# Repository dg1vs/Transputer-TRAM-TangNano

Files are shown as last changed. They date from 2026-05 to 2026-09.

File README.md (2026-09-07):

# Transputer-TRAM-TangNano

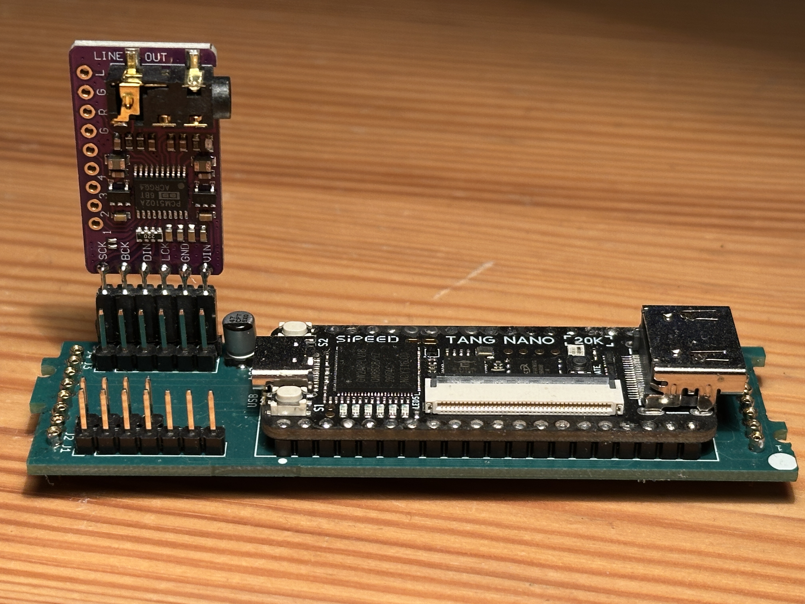
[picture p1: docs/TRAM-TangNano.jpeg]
Transputer-TRAM-TangNano V02


A **TRAM-size FPGA Transputer module** based on the **Sipeed Tang Nano 20K**.

The goal of this project is to provide a modern, compact Transputer module which can be used in systems designed for classic INMOS TRAMs, while replacing most of the increasingly difficult-to-obtain historical hardware with an FPGA implementation.

The project targets FPGA implementations of the **T805** and **T425** Transputers and is intended both for practical use in existing Transputer systems and for experimenting with Transputer hardware today.

The main idea behind this project is to provide a TRAM with an FPGA based implementation. For FPGA imlemetation please see the paper [1]. 

## Main Features

- TRAM-size PCB
- Sipeed **Tang Nano 20K** FPGA module
- FPGA implements the **INMOS T805 and T425**
- Standard Transputer link interface
- Four Transputer links
- Support for the usual TRAM control signals
- 5 V / 3.3 V level adaptation between classic Transputer hardware and the FPGA
- I²S audio support
- Selected Transputer and FPGA signals available on pin headers
- Can be used in systems with standard TRAM slots, including the **ATW800/2**
- Ready-to-program Gowin `.fs` FPGA image available

## Background

Original Transputer systems are still interesting platforms for experimenting with parallel computing, message-passing architectures and historical computer hardware.

One problem when building or restoring such systems is the availability of suitable Transputer processors and associated interface components.

At the same time, inexpensive modern FPGA modules such as the **Tang Nano 20K** provide enough resources to implement a Transputer together with additional peripheral logic in a very small form factor.

The idea behind **Transputer-TRAM-TangNano** is therefore simple:

> Put a modern FPGA implementation of a Transputer into the mechanical and electrical environment of a classic TRAM.

This makes it possible to use the module together with existing Transputer hardware without requiring another custom host interface.

## FPGA Transputer

The Tang Nano 20K carries the FPGA implementation of the Transputer.

The T425 is representative of the widely used 32-bit integer Transputers, while the T805 adds floating-point capabilities and was one of the most powerful members of the classic Transputer family.

The FPGA implementation used by this project is based on joint work by **Andre** , **Claus (cpm)** and **me (dg1vs)**.

### FPGA source code

A ready-to-program **Gowin `.fs` bitstream file** is available.

The FPGA HDL source code itself is currently **not published** as part of this repository.

This means that the supplied FPGA image can be used to operate the hardware, but rebuilding or modifying the FPGA design requires access to the original FPGA sources.

## TRAM Interface

The module follows the basic interface concept of a classic Transputer TRAM.

The hardware provides the four standard Transputer communication links:

- Link 0
- Link 1
- Link 2
- Link 3

Each link consists of a `LinkIn` and `LinkOut` signal.

The TRAM interface also provides the normal Transputer control signals including:

- `ClockIn`
- `Analyse`
- `Reset`
- `notError`
- Link-speed is set fixed to 20 Mbps

This allows the FPGA-based Transputer to behave like a conventional Transputer module from the point of view of the host system.

## 5 V / 3.3 V Level Adaptation

One of the less obvious challenges when combining original Transputer hardware with a modern FPGA is the difference in logic levels.

Classic TRAM and Transputer hardware operates in a **5 V environment**, while the Tang Nano 20K and its FPGA I/O use **3.3 V logic**.

Considerable attention was therefore given to the interface between these two voltage domains.

The current hardware design uses dedicated level-translation circuitry for the Transputer links. Four **TXU0202 dual-channel level translators** provide the eight signal paths required for the four `LinkIn` / `LinkOut` pairs.

Additional circuitry is used for the Transputer control, clock and status signals.

The intention is to make the module compatible with real Transputer hardware while protecting the modern FPGA from inappropriate signal levels.

## Breakout Connectors

Several signals are additionally available on 2.54 mm pin headers.

These connectors are useful for:

- Sound interface (quite cool for an transputer)
- debugging
- logic-analyzer measurements
- FPGA experiments
- connecting additional peripherals
- accessing selected Transputer signals
- experimenting with Transputer links

The PCB contains dedicated connectors for link, event and audio-related signals.

This makes the board useful not only as a replacement TRAM but also as a development platform for Transputer experiments.

## Audio / I²S

Audio output is supported using the **I²S/PCM facilities of the Tang Nano 20K**.

The Tang Nano 20K contains onboard audio hardware, and the TRAM carrier additionally provides an audio connector for access to the relevant signals.

This allows Transputer or FPGA applications to generate sound without requiring a separate audio subsystem.

## ATW800/2

The module can be used with the **ATW800/2** Atari Transputer system.

The ATW800/2 provides conventional size-1 TRAM slots for physical Transputer modules, making the Transputer-TRAM-TangNano a natural companion for this system.

## Hardware

The PCB was designed with **KiCad**.

The main project files are located in:

```text
hardware/tram_tangnano/
    tram_tangnano.kicad_pro
    tram_tangnano.kicad_sch
    tram_tangnano.kicad_pcb
```

The project uses the separate **Transputer-Kicad-Library** as a Git submodule:

```text
hardware/libs/Transputer-Kicad-Library
```

After cloning the repository, initialize the submodule with:

```bash
git submodule update --init --recursive
```

## FPGA Programming

The supplied `.fs` file is a ready-to-program Gowin FPGA bitstream for the Tang Nano 20K.

It can be programmed using the usual Tang Nano 20K programming tools, for example:

- Gowin Programmer
- openFPGALoader

The FPGA source project is currently not included in this repository.

## Project Status

This is an experimental retro-computing hardware project.

The board has already gone through several hardware revisions, particularly around the 5 V / 3.3 V interface.

See `CHANGELOG.md` for known issues and changes between PCB revisions.

When building a board, always check the current schematic, PCB revision and changelog before ordering PCBs or assembling components.

## Credits

- **Andre**
- **Claus (cpm)**

## References

A useful technical background reference for implementing the Transputer architecture in an FPGA is:

[1] Uwe, Mielke & Martin, Zabel & Michael, Bruestle. (2019). T42 – Transputer in FPGA. 10.3233/978-1-61499-949-2-525.  

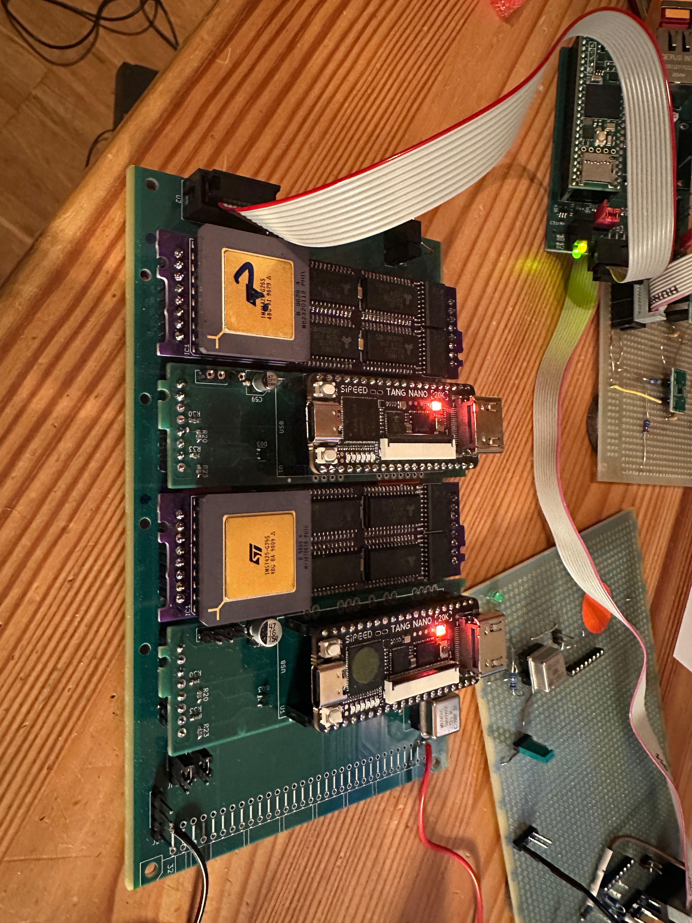
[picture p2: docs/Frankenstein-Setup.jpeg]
A monster setup with the first version


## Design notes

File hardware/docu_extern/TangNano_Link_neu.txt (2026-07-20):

Neue Variante TangNano Standalone Linkbelegung
28.05.2026 A.Saischowa

Diese Belegung orientiert sich an der ATW800/2 und soll sicherstellen, das der  ATW800-Transputer 
bei gesteckten TRAM im Slot1 mit TangNano20k Standalone als erstes den T805 sieht, da dieser Zugriff auf 
alle HW-Register für HDMI/I2S hat. Bei einem weiteren Tram im Slot 2 (tangnano,T805) ist auch der T805 
der erste in der Kette.

         NotResetIn      IOT40A 73   USB        +5V
         NotAnalyseIn    IOT34B 74              GND
         NotErrorOut     IOT34A 75           76 IOT30B   EventWaiting
                         IOT4B  85           80 IOT26A
                         IOT30A 77           42 IOB42B   ExtLink3Out       T4_L0Out
         LED0            IOL47A 15           41 IOB43A   ExtLink3In        T4_L0In
         LED1            IOL47B 16           56 IOR36A   I2S_BCLK Audio 
T8_L0In  ExtLink0In      IOB8A  27           54 IOR38A   I2S_DIN  Audio 
T8_L0Out ExtLink0Out     IOB8B  28           51 IOR45A   PA_EN    Audio 
T8_L2In  ExtLink1In      IOB6A  25           48 IOR49B   ExtLink4In        T8_L3In
T8_L2Out ExtLink1Out     IOB6B  26           55 IOR36B   I2S_LRCK Audio
T4_L1In  ExtLink2In      IOB14A 29           49 IOR49A   ExtLink4Out       T8_L3Out
T4_L1Out ExtLink2Out     IOB14B 30           86 IOT4A    EventAck
         EventReq        IOB29A 31           79 IOT27B   WS2812 LED
         LED2            IOL49A 17              GND
         LED5            IOL51B 20              3V3
         LED4            IOL51A 19           72 IOT40B   ExtLink5In        T4_L2In 
         LED3            IOL49B 18           71 IOT40A   ExtLink5Out       T4_L2Out  
                              3V3            53 IOR38B
                              GND   HDMI     52 IOR39A

Am TRAM liegen dann die Links wie folgt  

Tram0In     T8_L0In
Tram0Out    T8_L0Out
Tram1In     T8_L2In
Tram1Out    T8_L2Out   
Tram2In     T4_L0In
Tram2Out    T4_L0Out
Tram3In     T8_L3In
Tram3Out    T8_L3Out     

Lötpkt      T4_L1In
Lötpkt      T4_L1Out
Lötpkt      T4_L2In
Lötpkt      T4_L2Out

Intern sind T805 L1 <> T425 L3 verbunden

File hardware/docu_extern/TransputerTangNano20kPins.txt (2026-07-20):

NotResetIn      IOT40A 73   USB        +5V
NotAnalyseIn    IOT34B 74              GND
NotErrorOut     IOT34A 75           76 IOT30B	EventWaiting
                IOT4B  85           80 IOT26A
                IOT30A 77           42 IOB42B   ExtLink3Out
LED0            IOL47A 15           41 IOB43A   ExtLink3In
LED1            IOL47B 16           56 IOR36A   I2S_BCLK Audio 
ExtLink0In      IOB8A  27           54 IOR38A   I2S_DIN  Audio 
ExtLink0Out     IOB8B  28           51 IOR45A   PA_EN    Audio 
ExtLink1In      IOB6A  25           48 IOR49B   ExtLink4In
ExtLink1Out     IOB6B  26           55 IOR36B   I2S_LRCK Audio
ExtLink2In      IOB14A 29           49 IOR49A   ExtLink4Out
ExtLink2Out     IOB14B 30           86 IOT4A    EventAck
EventReq        IOB29A 31           79 IOT27B   WS2812 LED
LED2            IOL49A 17              GND
LED5            IOL51B 20              3V3
LED4            IOL51A 19           72 IOT40B   ExtLink5In
LED3            IOL49B 18           71 IOT40A   ExtLink5Out
                   3V3              53 IOR38B
                   GND      HDMI    52 IOR39A

HDMI 35,36 37,38 39,40 33,34
Button 87
Reset 88
sysclk 4
UartTX 69
UartRX 70

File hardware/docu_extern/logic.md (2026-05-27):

# SN74AUP1G06

Inverter with open drain
Only 3.3 V

# SN74LVC1GU04

1 Inverter
Inputs Accept Voltages to 5.5 V

# SN74LVC2GU04

2 Inverter
Inputs Accept Voltages to 5.5 V

# SN74LVC1G06

Inverter with open drain

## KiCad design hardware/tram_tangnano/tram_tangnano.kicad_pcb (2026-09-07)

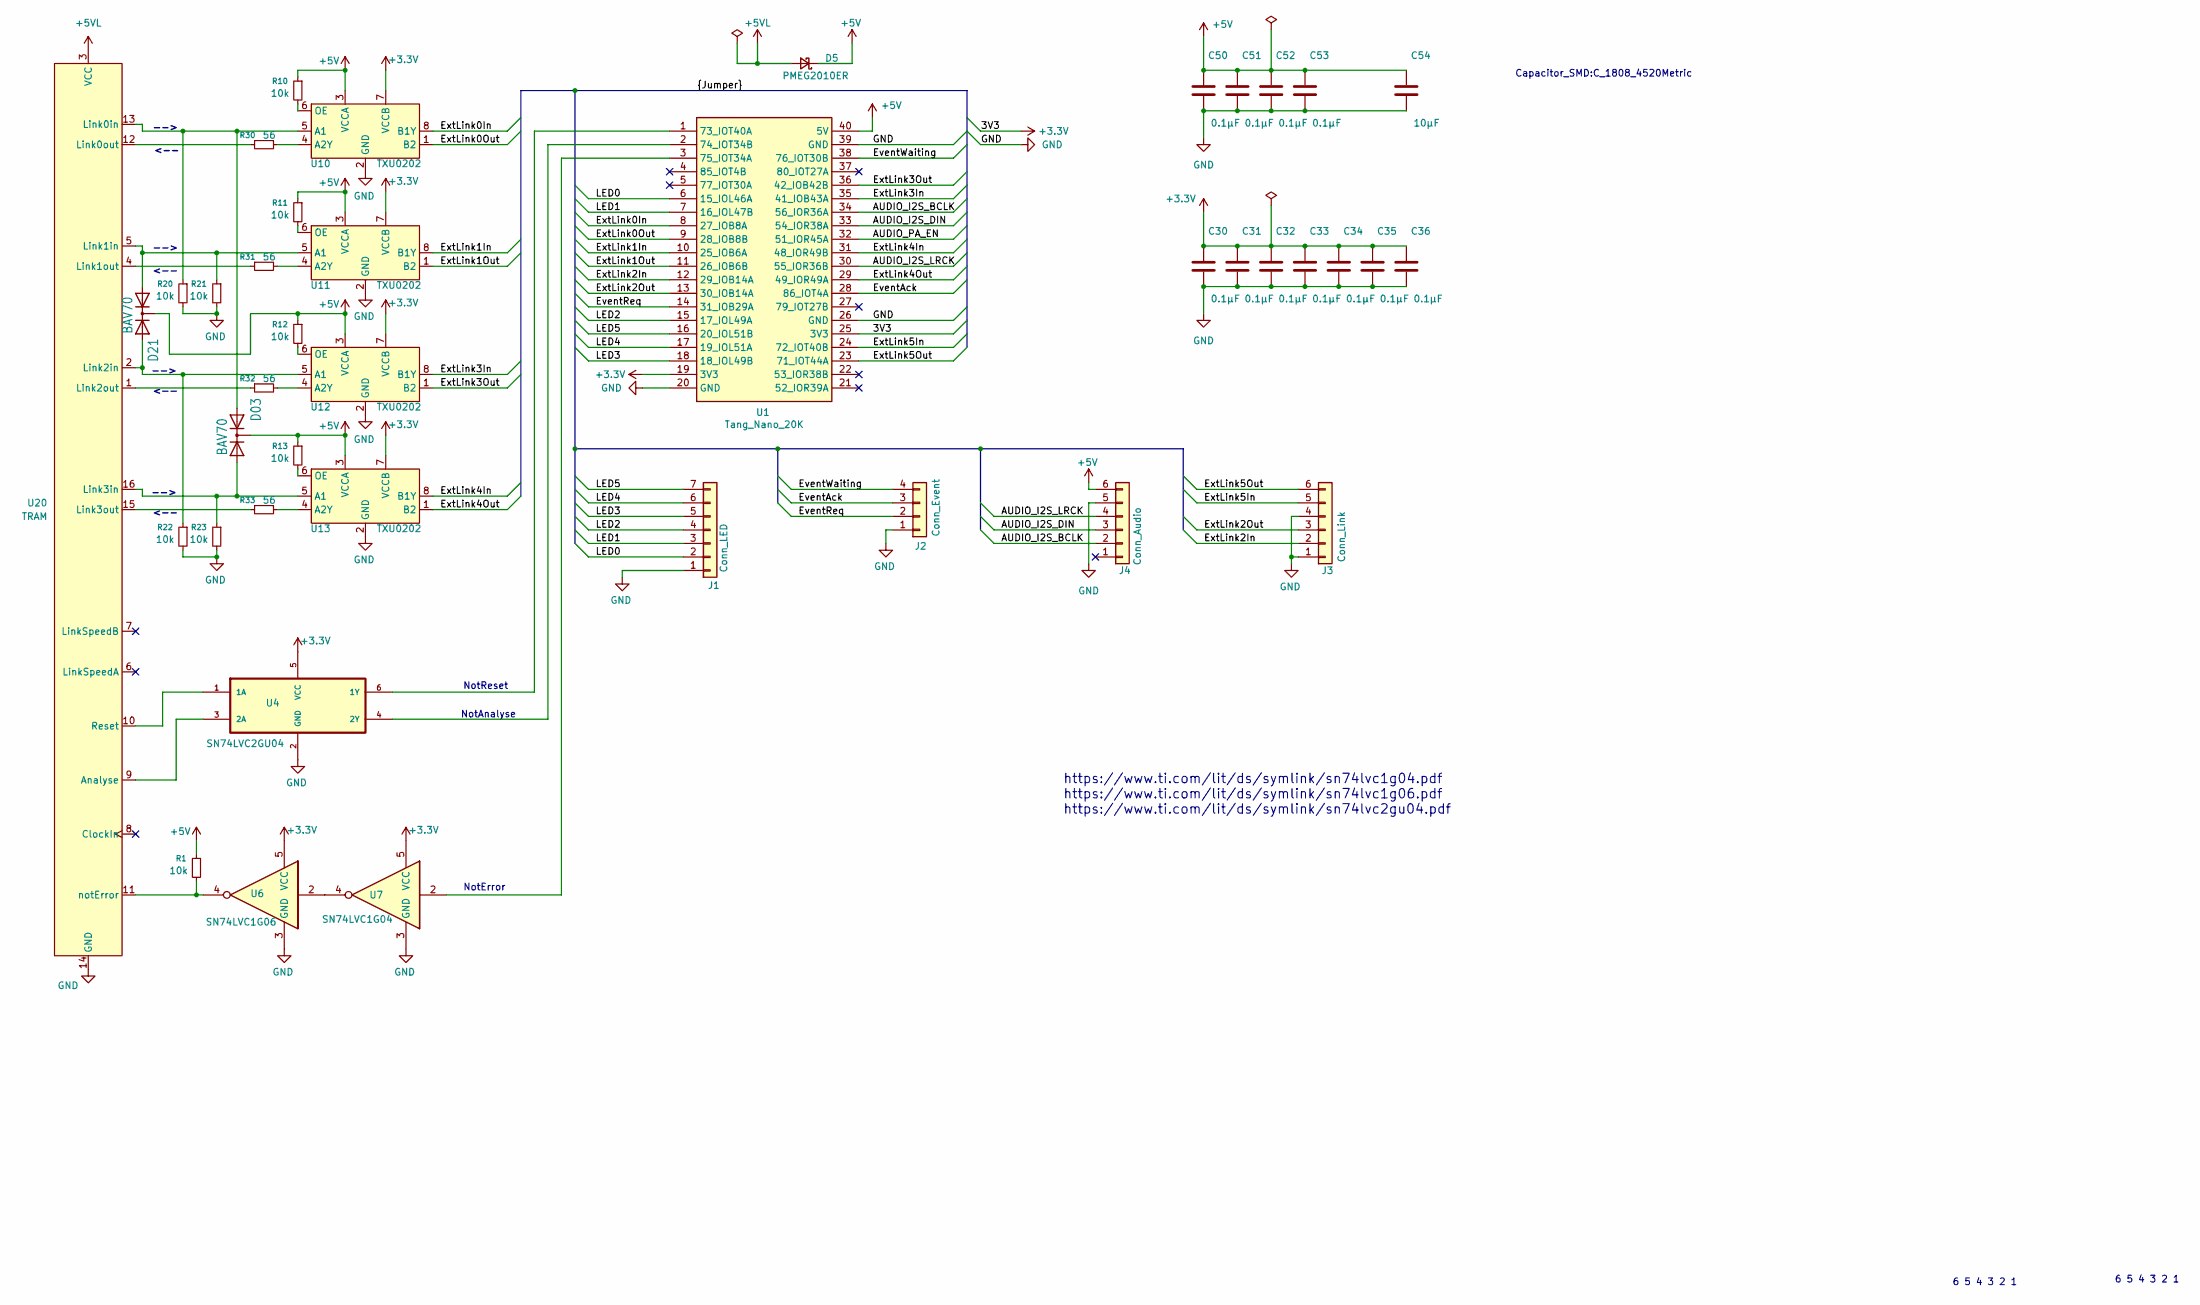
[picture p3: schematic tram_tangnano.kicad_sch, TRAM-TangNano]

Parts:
C30, C31, C32, C33, C34, C35, C36, C50, C51, C52, C53: 0.1µF; C_0603_1608Metric_Pad1.08x0.95mm_HandSolder; LCSC C14663
C54: 10µF; C_Elec_3x5.4
D03, D21: BAV70; SOT-23; LCSC C68978
D5: PMEG2010ER; Nexperia_CFP3_SOD-123W
J1: Conn_LED; PinHeader_1x07_P2.54mm_Vertical
J2: Conn_Event; PinHeader_1x04_P2.54mm_Vertical
J3: Conn_Link; PinHeader_1x06_P2.54mm_Vertical
J4: Conn_Audio; PinHeader_1x06_P2.54mm_Vertical
R1, R10, R11, R12, R13, R20, R21, R22, R23: 10k; R_0603_1608Metric_Pad0.98x0.95mm_HandSolder; LCSC C25804
R30, R31, R32, R33: 56; R_0603_1608Metric_Pad0.98x0.95mm_HandSolder; LCSC C25196
U1: Tang_Nano_20K; DIP-40_TangNano20K
U4: SN74LVC2GU04; SOT-23-6_Handsoldering; LCSC C41430939
U6: SN74LVC1G06; SOT-23-5_HandSoldering; LCSC C22469967
U7: SN74LVC1G04; SOT-23-5_HandSoldering; LCSC C19829658
U10, U11, U12, U13: TXU0202; VSSOP-8_2.3x2mm_P0.5mm; LCSC C7372013
U20: TRAM; TRAM-1-PCB

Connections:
+3.3V: C30.1, C31.1, C32.1, C33.1, C34.1, C35.1, C36.1, U1.19 (3V3), U1.25 (3V3), U4.5 (VCC), U6.5 (VCC), U7.5 (VCC), U10.7 (VCCB), U11.7 (VCCB), U12.7 (VCCB), U13.7 (VCCB)
+5V: C50.1, C51.1, C52.1, C53.1, C54.1, D03.3 (C), D5.1 (K), D21.3 (C), J4.6, R1.1, R10.1, R11.1, R12.1, R13.1, U1.40 (5V), U10.3 (VCCA), U11.3 (VCCA), U12.3 (VCCA), U13.3 (VCCA)
+5VL: D5.2 (A), U20.3 (VCC)
/AUDIO_I2S_BCLK: J4.2, U1.34 (56_IOR36A)
/AUDIO_I2S_DIN: J4.3, U1.33 (54_IOR38A)
/AUDIO_I2S_LRCK: J4.4, U1.30 (55_IOR36B)
/AUDIO_PA_EN: U1.32 (51_IOR45A)
/EventAck: J2.3, U1.28 (86_IOT4A)
/EventReq: J2.2, U1.14 (31_IOB29A)
/EventWaiting: J2.4, U1.38 (76_IOT30B)
/ExtLink0In: U1.8 (27_IOB8A), U10.8 (B1Y)
/ExtLink0Out: U1.9 (28_IOB8B), U10.1 (B2)
/ExtLink1In: U1.10 (25_IOB6A), U11.8 (B1Y)
/ExtLink1Out: U1.11 (26_IOB6B), U11.1 (B2)
/ExtLink2In: J3.2, U1.12 (29_IOB14A)
/ExtLink2Out: J3.3, U1.13 (30_IOB14A)
/ExtLink3In: U1.35 (41_IOB43A), U12.8 (B1Y)
/ExtLink3Out: U1.36 (42_IOB42B), U12.1 (B2)
/ExtLink4In: U1.31 (48_IOR49B), U13.8 (B1Y)
/ExtLink4Out: U1.29 (49_IOR49A), U13.1 (B2)
/ExtLink5In: J3.5, U1.24 (72_IOT40B)
/ExtLink5Out: J3.6, U1.23 (71_IOT44A)
/LED0: J1.2, U1.6 (15_IOL46A)
/LED1: J1.3, U1.7 (16_IOL47B)
/LED2: J1.4, U1.15 (17_IOL49A)
/LED3: J1.5, U1.18 (18_IOL49B)
/LED4: J1.6, U1.17 (19_IOL51A)
/LED5: J1.7, U1.16 (20_IOL51B)
GND: C30.2, C31.2, C32.2, C33.2, C34.2, C35.2, C36.2, C50.2, C51.2, C52.2, C53.2, C54.2, J1.1, J2.1, J3.1, J3.4, J4.5, R20.2, R21.2, R22.2, R23.2, U1.20 (GND), U1.26 (GND), U1.39 (GND), U4.2 (GND), U6.3 (GND), U7.3 (GND), U10.2 (GND), U11.2 (GND), U12.2 (GND), U13.2 (GND), U20.14 (GND)
unnamed: D03.1 (A1), R23.1, U13.5 (A1), U20.16 (Link3in)
unnamed: D03.2 (A2), R20.1, U10.5 (A1), U20.13 (Link0in)
unnamed: D21.1 (A1), R22.1, U12.5 (A1), U20.2 (Link2in)
unnamed: D21.2 (A2), R21.1, U11.5 (A1), U20.5 (Link1in)
unnamed: U1.1 (73_IOT40A), U4.6 (1Y)
unnamed: U1.2 (74_IOT34B), U4.4 (2Y)
unnamed: U1.3 (75_IOT34A), U7.2
unnamed: U6.2, U7.4
unnamed: R30.2, U10.4 (A2Y)
unnamed: R10.2, U10.6 (OE)
unnamed: R31.2, U11.4 (A2Y)
unnamed: R11.2, U11.6 (OE)
unnamed: R32.2, U12.4 (A2Y)
unnamed: R12.2, U12.6 (OE)
unnamed: R33.2, U13.4 (A2Y)
unnamed: R13.2, U13.6 (OE)
unnamed: U4.3 (2A), U20.9 (Analyse)
unnamed: R30.1, U20.12 (Link0out)
unnamed: R31.1, U20.4 (Link1out)
unnamed: R32.1, U20.1 (Link2out)
unnamed: R33.1, U20.15 (Link3out)
unnamed: U4.1 (1A), U20.10 (Reset)
unnamed: R1.2, U6.4, U20.11 (notError)

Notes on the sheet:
-->
6 5 4 3 2 1
https://www.ti.com/lit/ds/symlink/sn74lvc1g04.pdf https://www.ti.com/lit/ds/symlink/sn74lvc1g06.pdf https://www.ti.com/lit/ds/symlink/sn74lvc2gu04.pdf
<--
Capacitor_SMD:C_1808_4520Metric
NotReset
NotAnalyse
NotError

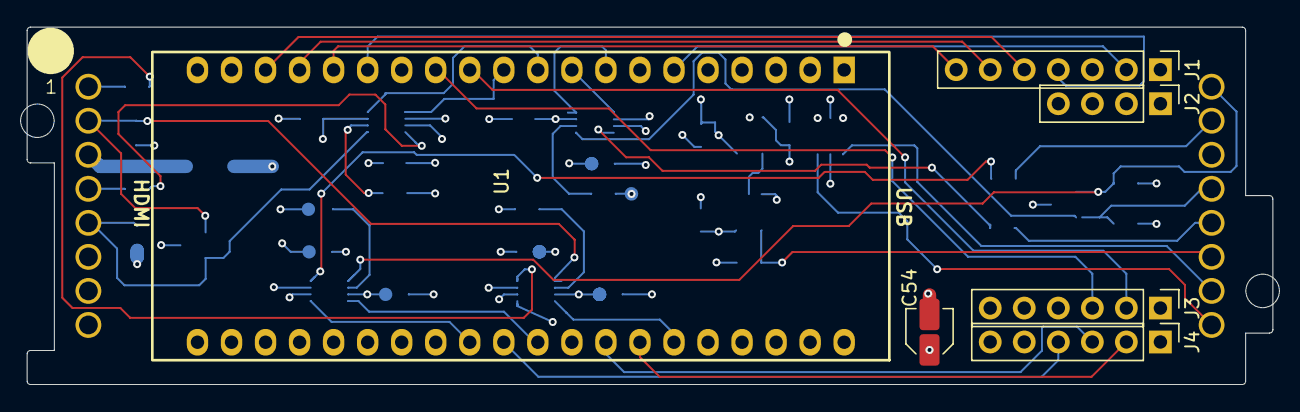
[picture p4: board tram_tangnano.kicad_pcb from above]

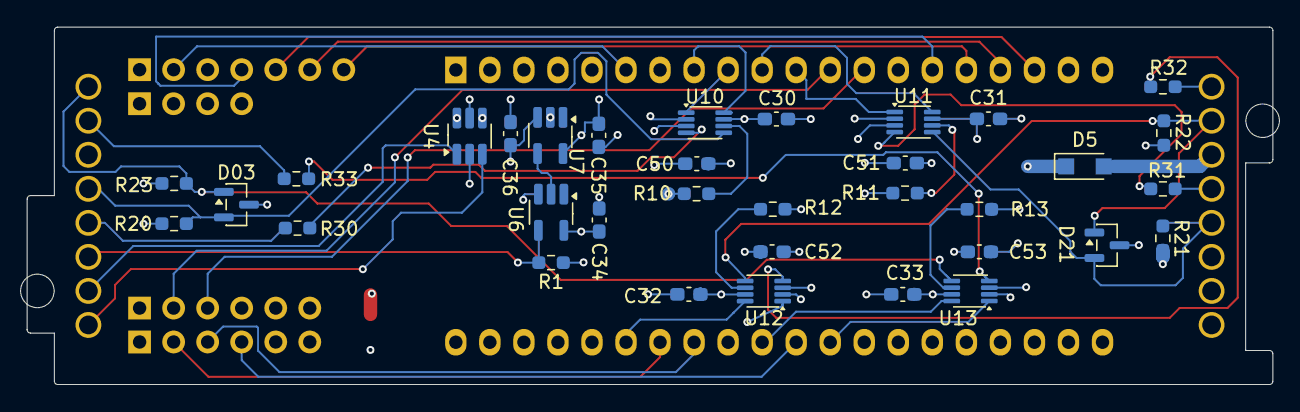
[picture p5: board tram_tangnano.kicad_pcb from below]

Board: 4 copper layers, 93.0 x 26.7 mm, 41 parts (34 on the bottom side), 51 nets.

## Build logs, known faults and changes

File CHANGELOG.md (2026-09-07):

# Changelog

## August 2026 Version 0.2
* More pin (e.g. sound)
* Just works

## May 2026 Version 0.1
First version of TangNano TRAM
See pictures

### Bug
* Not complete 3.3V plane
* "Fancy" problems with SN74LVC2G04
* One TangNano without T425

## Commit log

2026-06-03 Change to 10.x
    [tram_tangnano.kicad_pcb, tram_tangnano.kicad_sch]
2026-06-03 Update Lib
    [tram_tangnano.kicad_pcb, tram_tangnano.kicad_sch]
2026-07-20 cleanup pluto
    [tram_tangnano.kicad_pcb, tram_tangnano.kicad_sch]
2026-09-07 update docu
    [tram_tangnano.kicad_pcb, tram_tangnano.kicad_sch]
